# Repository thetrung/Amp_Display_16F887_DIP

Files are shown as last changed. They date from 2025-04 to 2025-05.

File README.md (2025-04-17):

# Amplifier Display with PIC16F887 (DIP Version)
The classic 8-bit **PIC16F887** will display all inputs on signals scan to its OLED (SSD1306) display. No LDO or any power-safe since we assume this will be powered by a stable current. Hope after like 5 Devkit version, this can be somewhat usable.

### Overview
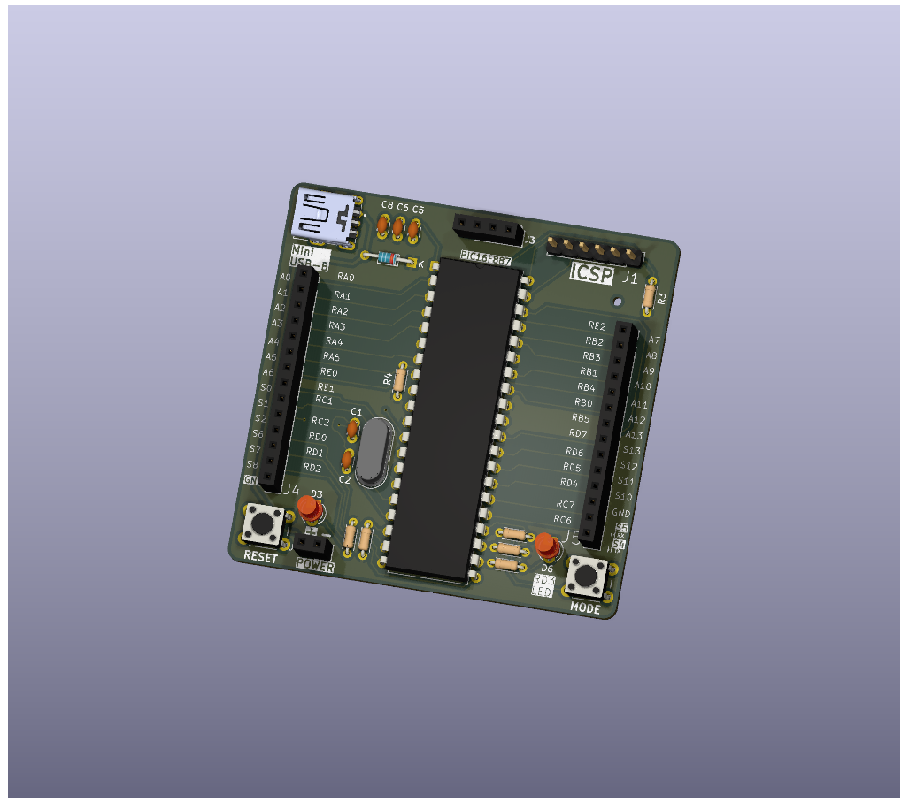
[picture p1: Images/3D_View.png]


### I/O Summpary
- I2C / UART / ICSP.
- 2-pins Power VCC/GND.
- Mini-USB-B (Power only).
- 1x Power & 1x (custom) LED.
- 1x Reset & 1x (custom) Mode Button.
- 14x Analog Inputs support.
- 14x Buttons support.

### Front View
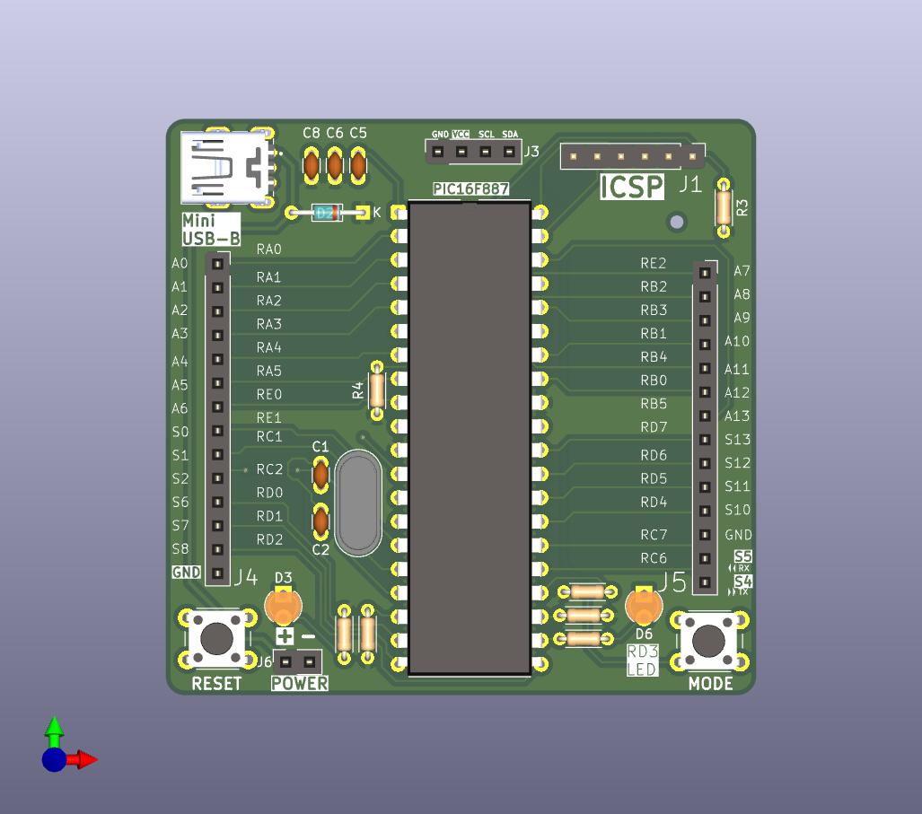
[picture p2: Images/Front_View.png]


### Back View
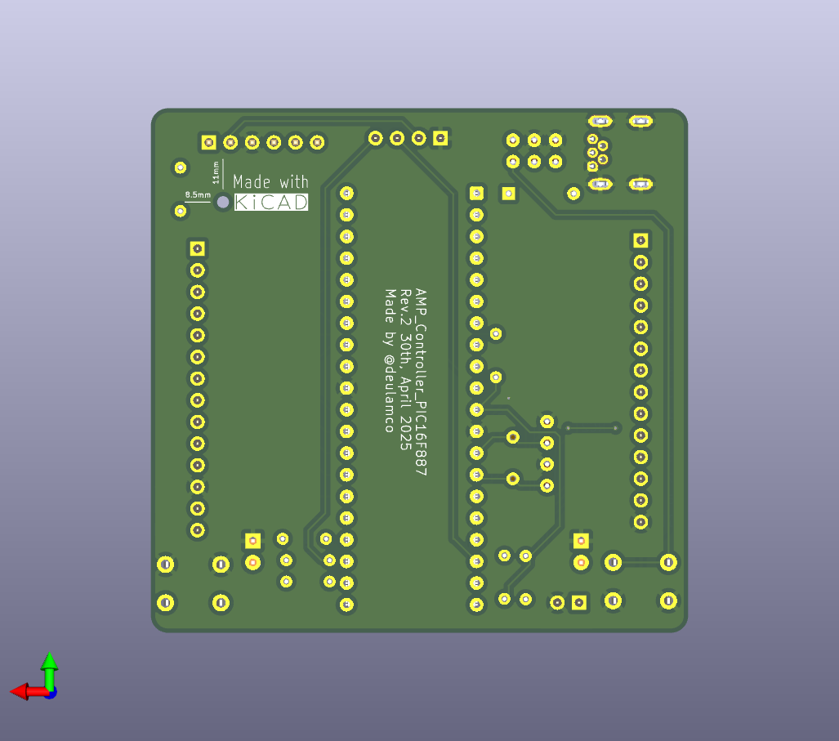
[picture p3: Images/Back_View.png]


### Schematic
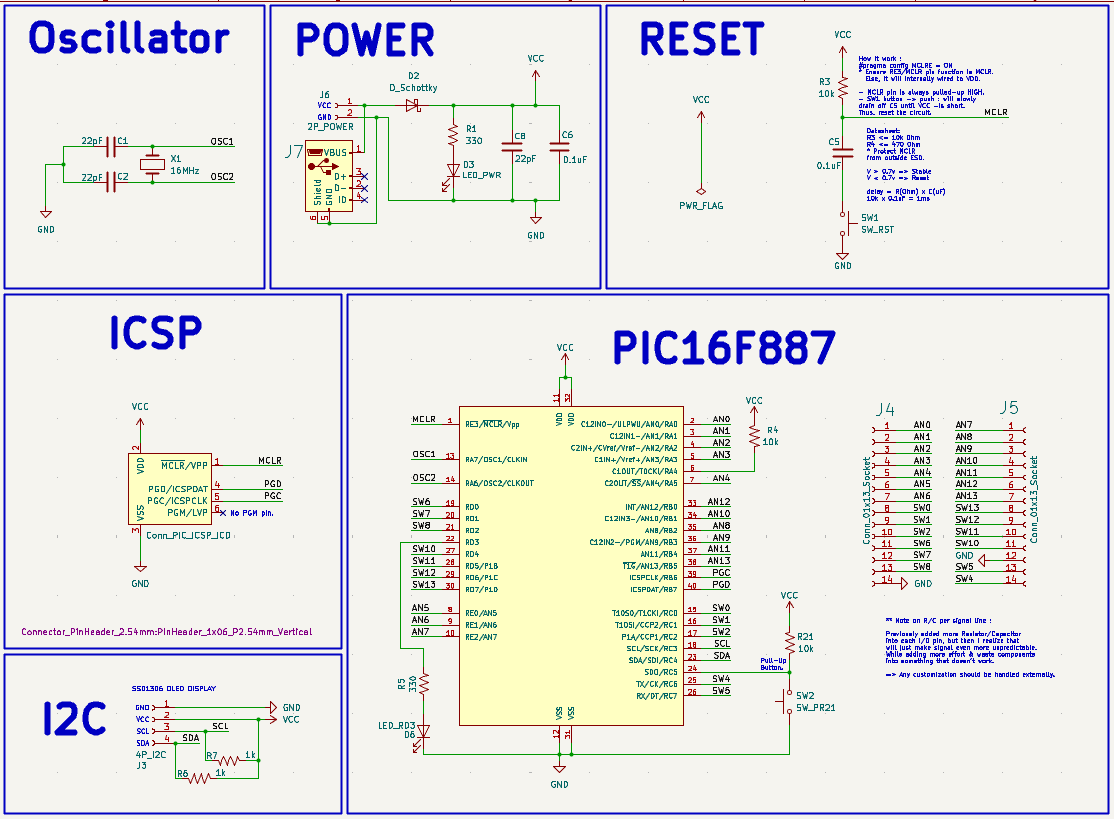
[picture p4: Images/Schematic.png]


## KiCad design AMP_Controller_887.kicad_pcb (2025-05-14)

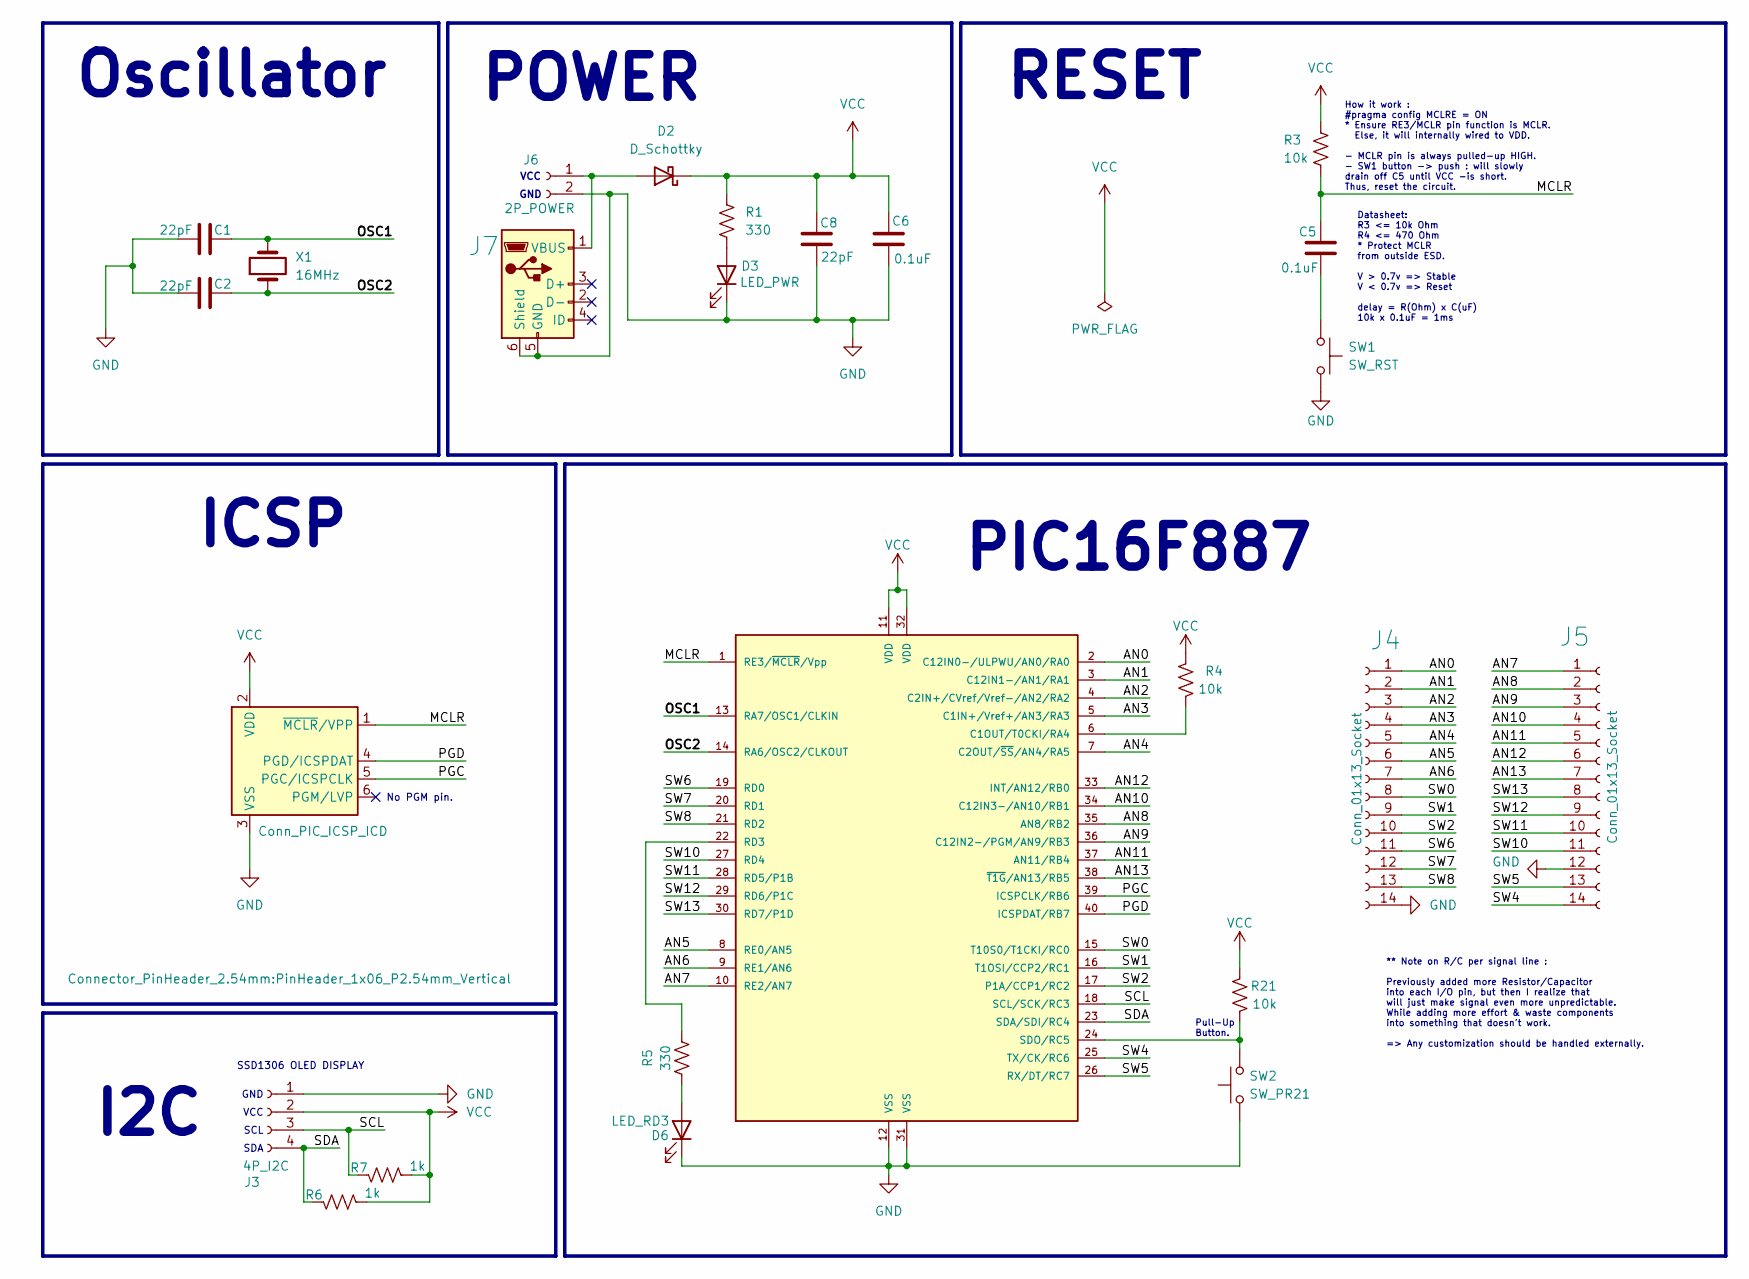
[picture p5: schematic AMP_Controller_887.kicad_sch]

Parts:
C1, C2, C8: 22pF; C_Disc_D3.0mm_W1.6mm_P2.50mm
C5, C6: 0.1uF; C_Disc_D3.0mm_W1.6mm_P2.50mm
D2: D_Schottky; D_DO-34_SOD68_P7.62mm_Horizontal
D3: LED_PWR; LED_D3.0mm_FlatTop
D6: LED_RD3; LED_D3.0mm_FlatTop
J1: Conn_PIC_ICSP_ICD; PinHeader_1x06_P2.54mm_Vertical
J3: 4P_I2C; PinSocket_1x04_P2.54mm_Vertical
J4, J5: Conn_01x13_Socket; PinSocket_1x14_P2.54mm_Vertical
J6: 2P_POWER; PinSocket_1x02_P2.54mm_Vertical
J7: USB_Mini_B_90_Angled; USB_MINI_B_90_Angled
PIC16F887: PIC16F887-I/P; DIP-40_W15.24mm
R1, R5: 330; R_Axial_DIN0204_L3.6mm_D1.6mm_P5.08mm_Horizontal
R3, R4, R21: 10k; R_Axial_DIN0204_L3.6mm_D1.6mm_P5.08mm_Horizontal
R6, R7: 1k; R_Axial_DIN0204_L3.6mm_D1.6mm_P5.08mm_Horizontal
SW1: SW_RST; SW_PUSH_6mm
SW2: SW_PR21; SW_PUSH_6mm
X1: 16MHz; Crystal_HC49-4H_Vertical

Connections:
/AN0: J4.1, PIC16F887.2 (C12IN0-/ULPWU/AN0/RA0)
/AN1: J4.2, PIC16F887.3 (C12IN1-/AN1/RA1)
/AN2: J4.3, PIC16F887.4 (C2IN+/CVref/Vref-/AN2/RA2)
/AN3: J4.4, PIC16F887.5 (C1IN+/Vref+/AN3/RA3)
/AN4: J4.5, PIC16F887.7 (C2OUT/~SS/AN4/RA5)
/AN5: J4.6, PIC16F887.8 (RE0/AN5)
/AN6: J4.7, PIC16F887.9 (RE1/AN6)
/AN7: J5.1, PIC16F887.10 (RE2/AN7)
/AN8: J5.2, PIC16F887.35 (AN8/RB2)
/AN9: J5.3, PIC16F887.36 (C12IN2-/PGM/AN9/RB3)
/AN10: J5.4, PIC16F887.34 (C12IN3-/AN10/RB1)
/AN11: J5.5, PIC16F887.37 (AN11/RB4)
/AN12: J5.6, PIC16F887.33 (INT/AN12/RB0)
/AN13: J5.7, PIC16F887.38 (~T1G/AN13/RB5)
/MCLR: C5.2, J1.1 (~MCLR/VPP), PIC16F887.1 (RE3/~MCLR/Vpp), R3.2
/OSC1: C1.1, PIC16F887.13 (RA7/OSC1/CLKIN), X1.2
/OSC2: C2.1, PIC16F887.14 (RA6/OSC2/CLKOUT), X1.1
/PGC: J1.5 (PGC/ICSPCLK), PIC16F887.39 (ICSPCLK/RB6)
/PGD: J1.4 (PGD/ICSPDAT), PIC16F887.40 (ICSPDAT/RB7)
/SCL: J3.3, PIC16F887.18 (SCL/SCK/RC3), R7.1
/SDA: J3.4, PIC16F887.23 (SDA/SDI/RC4), R6.1
/SW0: J4.8, PIC16F887.15 (T10S0/T1CKI/RC0)
/SW1: J4.9, PIC16F887.16 (T1OSI/CCP2/RC1)
/SW2: J4.10, PIC16F887.17 (P1A/CCP1/RC2)
/SW4: J5.14, PIC16F887.25 (TX/CK/RC6)
/SW5: J5.13, PIC16F887.26 (RX/DT/RC7)
/SW6: J4.11, PIC16F887.19 (RD0)
/SW7: J4.12, PIC16F887.20 (RD1)
/SW8: J4.13, PIC16F887.21 (RD2)
/SW10: J5.11, PIC16F887.27 (RD4)
/SW11: J5.10, PIC16F887.28 (RD5/P1B)
/SW12: J5.9, PIC16F887.29 (RD6/P1C)
/SW13: J5.8, PIC16F887.30 (RD7/P1D)
GND: C1.2, C2.2, C6.1, C8.2, D3.1 (K), D6.1 (K), J1.3 (VSS), J3.1, J4.14, J5.12, J6.2, J7.5 (GND), J7.6 (Shield), PIC16F887.12 (VSS), PIC16F887.31 (VSS), SW1.2, SW2.1
unnamed: C5.1, SW1.1
unnamed: D2.2 (A), J6.1, J7.1 (VBUS)
unnamed: D3.2 (A), R1.2
unnamed: D6.2 (A), R5.1
unnamed: PIC16F887.6 (C1OUT/T0CKI/RA4), R4.2
unnamed: PIC16F887.22 (RD3), R5.2
unnamed: PIC16F887.24 (SDO/RC5), R21.2, SW2.2
VCC: C6.2, C8.1, D2.1 (K), J1.2 (VDD), J3.2, PIC16F887.11 (VDD), PIC16F887.32 (VDD), R1.1, R3.1, R4.1, R6.2, R7.2, R21.1

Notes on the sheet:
RESET
POWER
ICSP
** Note on R/C per signal line : Previously added more Resistor/Capacitor into each I/O pin, but then I realize that will just make signal even more unpredictable. While adding more effort & waste components into something that doesn't work. => Any customization should be handled externally.
VCC
How it work : #pragma config MCLRE = ON * Ensure RE3/MCLR pin function is MCLR. Else, it will internally wired to VDD. - MCLR pin is always pulled-up HIGH. - SW1 button -> push : will slowly drain off C5 until VCC -is short. Thus, reset the circuit.
Pull-Up Button.
SDA
GND
I2C
Datasheet: R3 <= 10k Ohm R4 <= 470 Ohm * Protect MCLR from outside ESD. V > 0.7v => Stable V < 0.7v => Reset delay = R(Ohm) x C(uF) 10k x 0.1uF = 1ms
SCL
SSD1306 OLED DISPLAY
Oscillator
No PGM pin.
PIC16F887

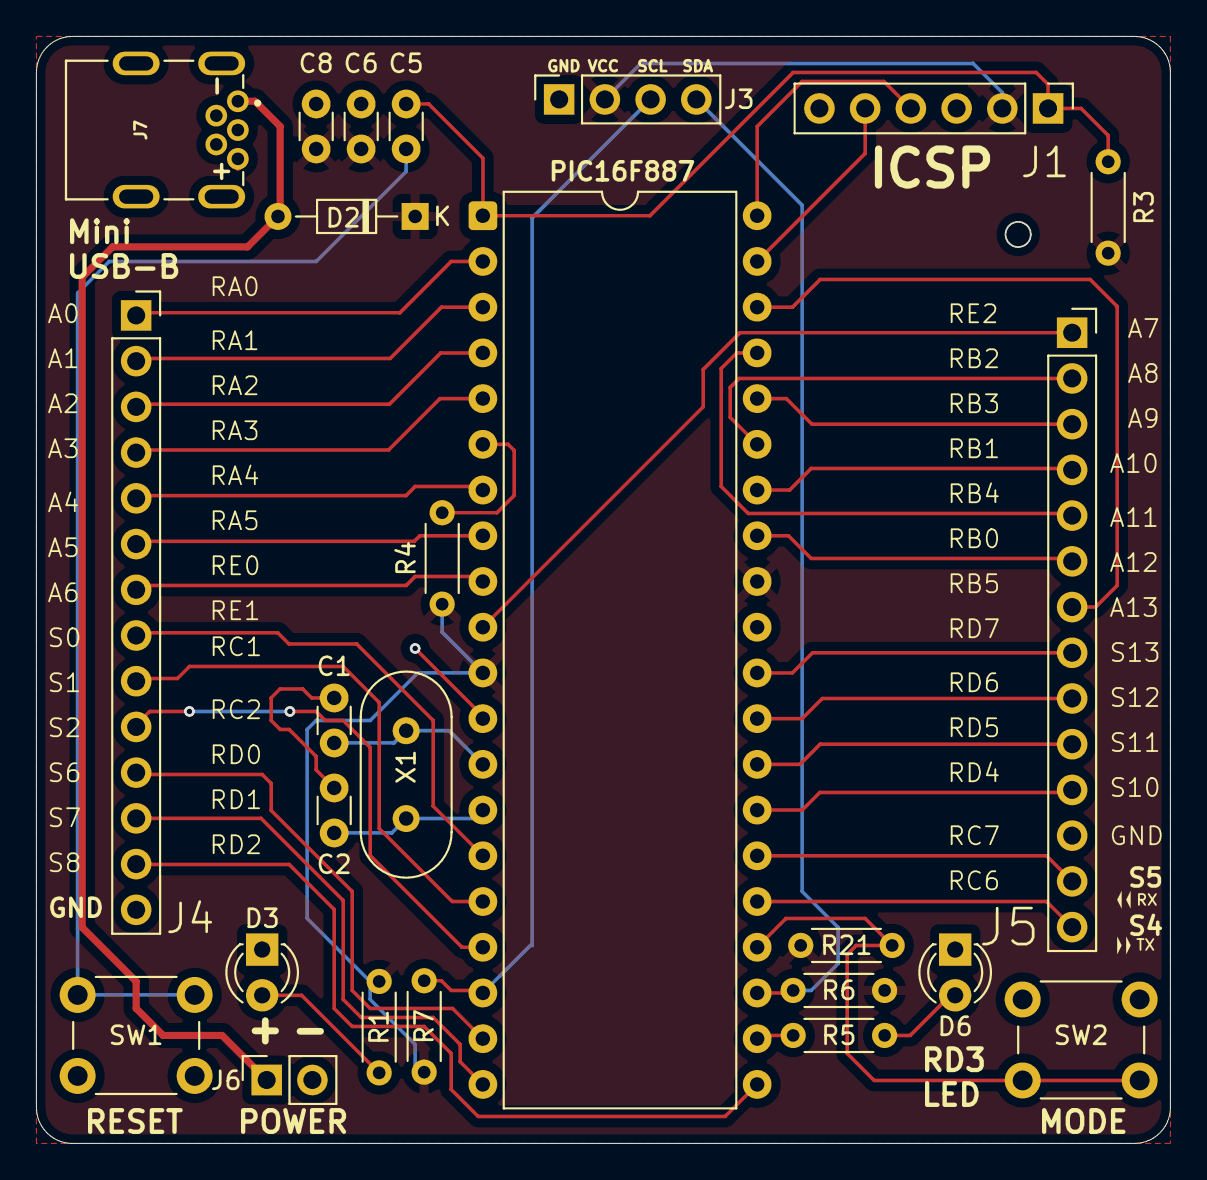
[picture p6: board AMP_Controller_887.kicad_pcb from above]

Board: 2 copper layers, 63.0 x 61.5 mm, 25 parts (0 on the bottom side), 42 nets.

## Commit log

2025-04-16 Refined Schematic + Sketch Layout
    [AMP_Controller_887.kicad_pcb, AMP_Controller_887.kicad_sch]
2025-04-17 Finished layout.
    [AMP_Controller_887.kicad_pcb, AMP_Controller_887.kicad_sch]
2025-04-17 Fix power pins position to not block OLED display.
    [AMP_Controller_887.kicad_pcb]
2025-04-19 Swap position of S5/S4 (aka: RX/TX) downward
    [AMP_Controller_887.kicad_pcb, AMP_Controller_887.kicad_sch]
2025-04-30 Rev.2 : Flip USB to be normal, remove all R/C from I/O, Fix pull-up button, refine fonts.
    [AMP_Controller_887.kicad_pcb, AMP_Controller_887.kicad_sch]
2025-05-14 Update name
    [AMP_Controller_887.kicad_pcb]
